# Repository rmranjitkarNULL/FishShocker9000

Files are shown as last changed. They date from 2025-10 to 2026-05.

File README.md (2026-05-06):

# FishShocker9000
A hardware/software system for high-voltage pulse generation and control, integrating custom PCB design, embedded firmware, and testing tools.

---

## Overview
FishShocker9000 was developed as a project to explore **embedded systems design, PCB layout, and high-voltage electronics**.  
The system combines custom hardware with **C/C++ firmware** to generate controlled electrical pulses, managed through a modular and extensible software stack.

---

## Hardware
- **Custom PCB Design** (schematics + board layouts)  
- Power delivery circuits for safe and reliable pulse generation  
- Signal conditioning and protection hardware  
- Mixed-signal layout considerations for high-voltage operation  

---

## Features
- Precise pulse generation and control  
- Configurable timing and waveform parameters  
- Modular design for hardware/firmware scalability  
- PCB + firmware tightly integrated for performance and safety  

---

## Repository Structure
FishShocker9000/
├── include/ # Header files
├── lib/ # Custom libraries
├── src/ # Firmware source code
├── test/ # Testing and validation scripts
├── pcb/ # PCB design files (schematics, layouts)
└── README.md # Project documentation

---

## Future Improvements
- Improve PCB design for efficiency and miniaturization  
- Expand safety features and protection circuitry  

---

TODO
-[ ] Redo Readme
-[ ] Make assembly guide
-[ ] [add](https://www.pjrc.com/teensy/loader.html)

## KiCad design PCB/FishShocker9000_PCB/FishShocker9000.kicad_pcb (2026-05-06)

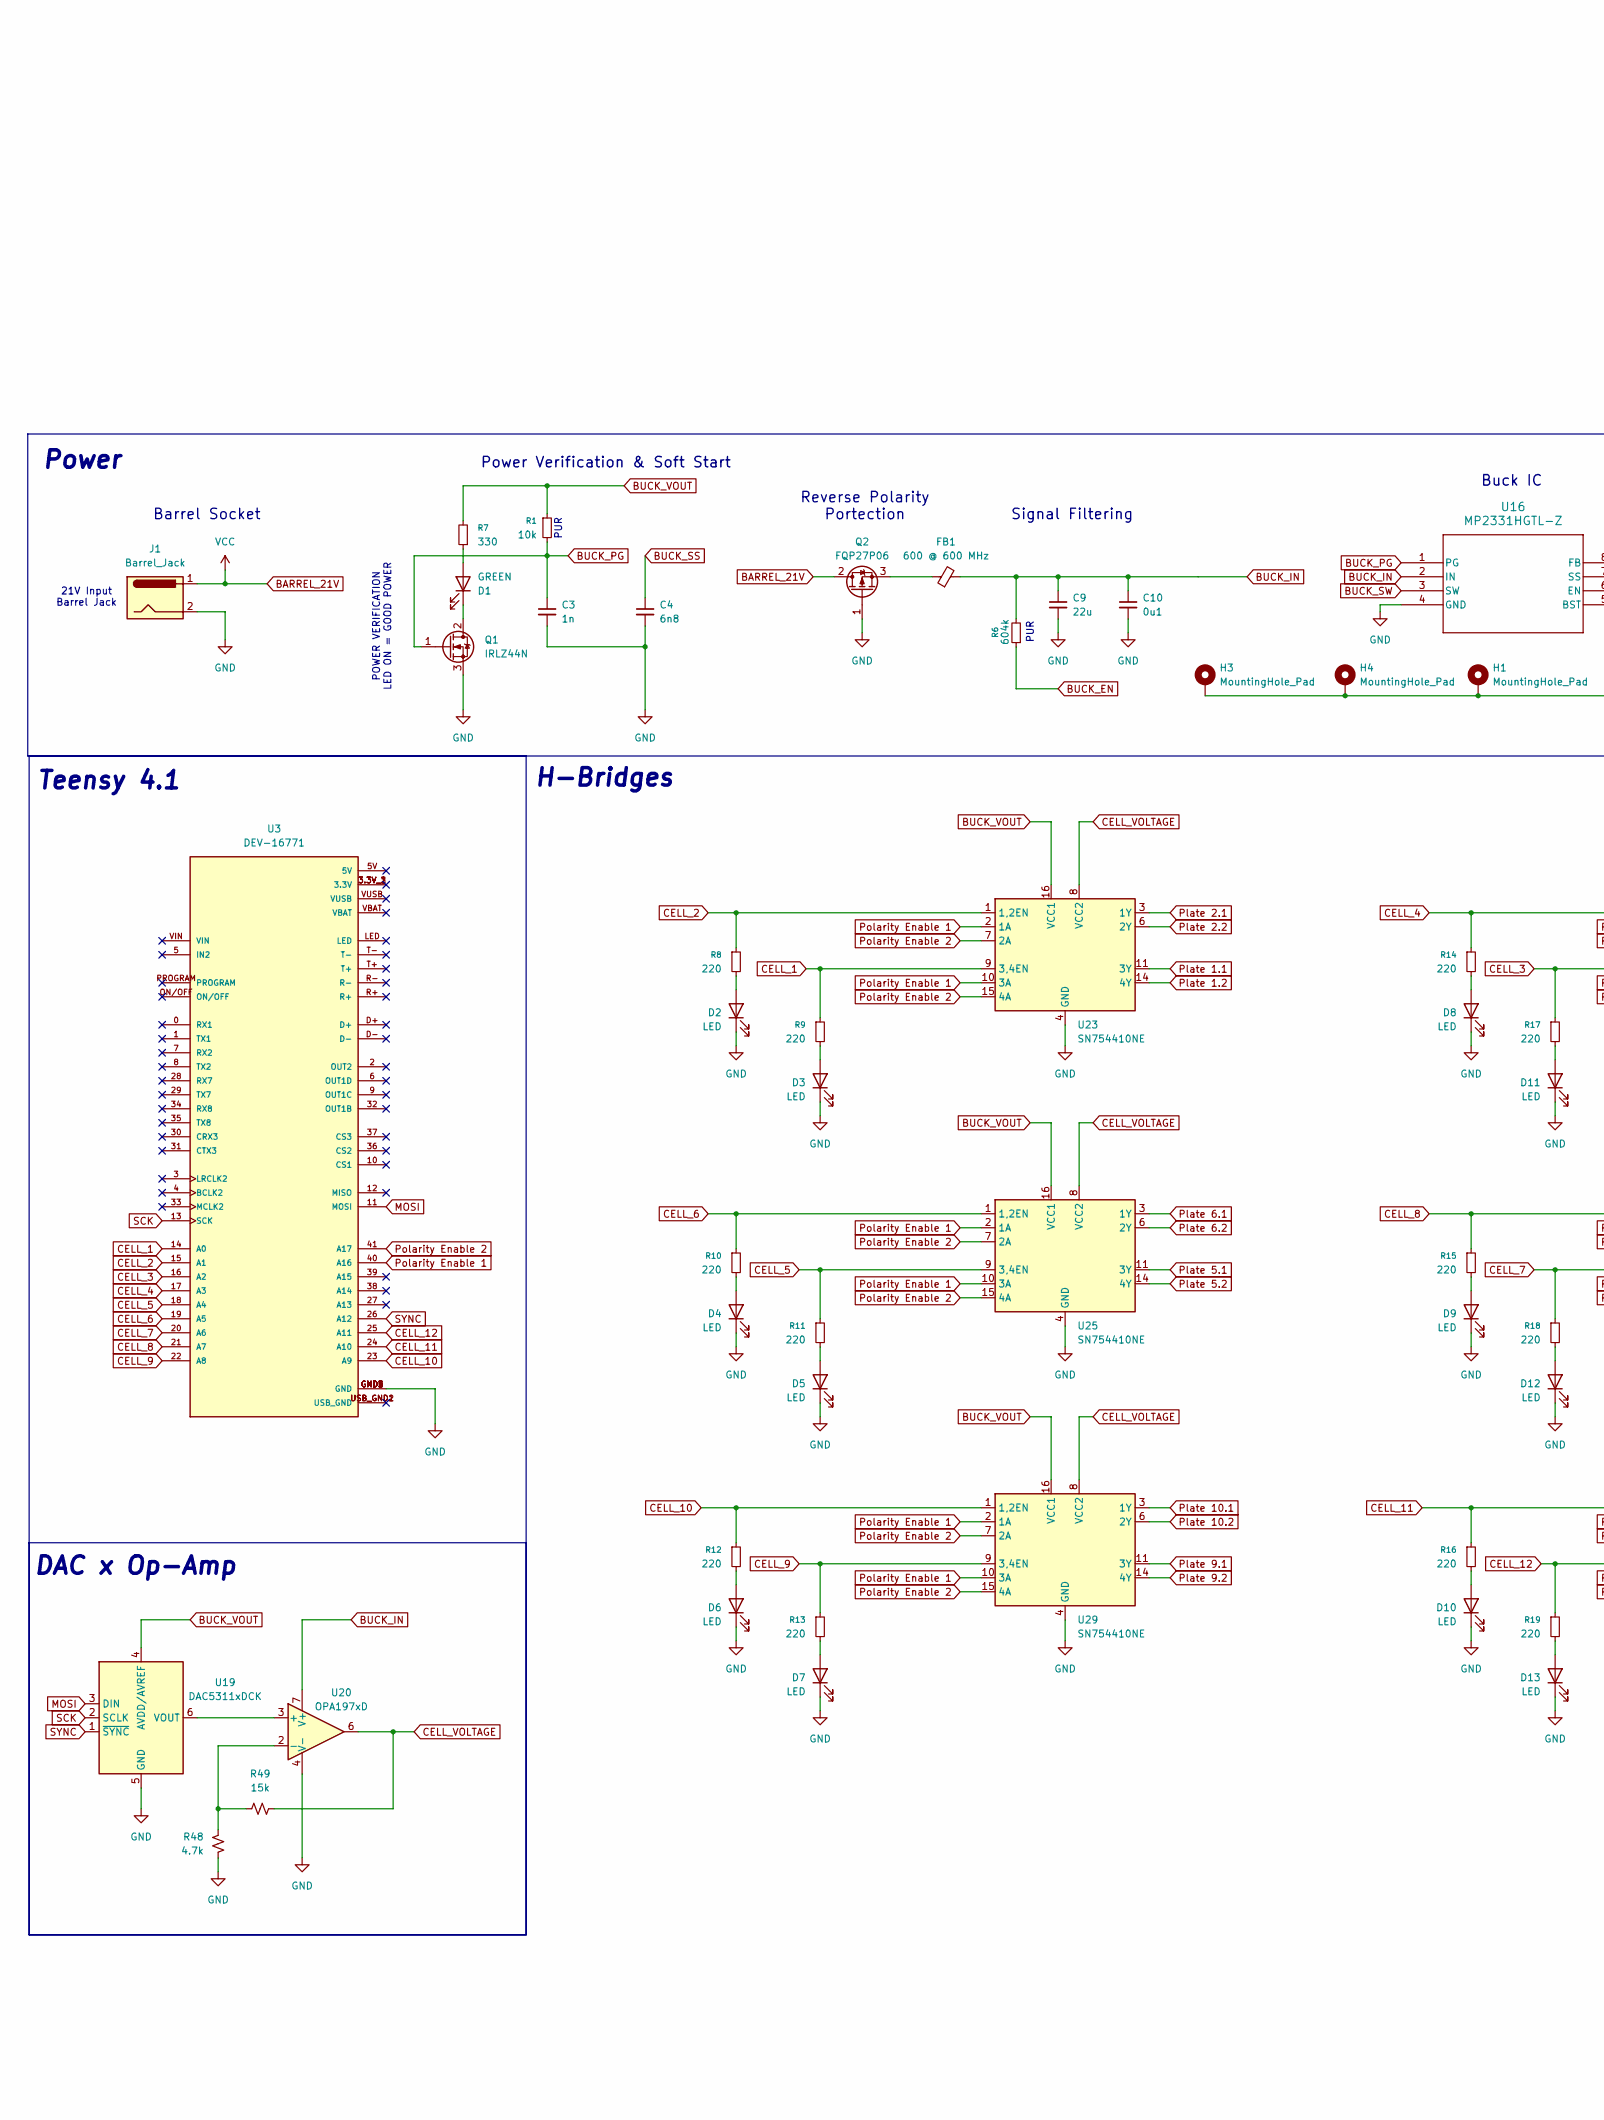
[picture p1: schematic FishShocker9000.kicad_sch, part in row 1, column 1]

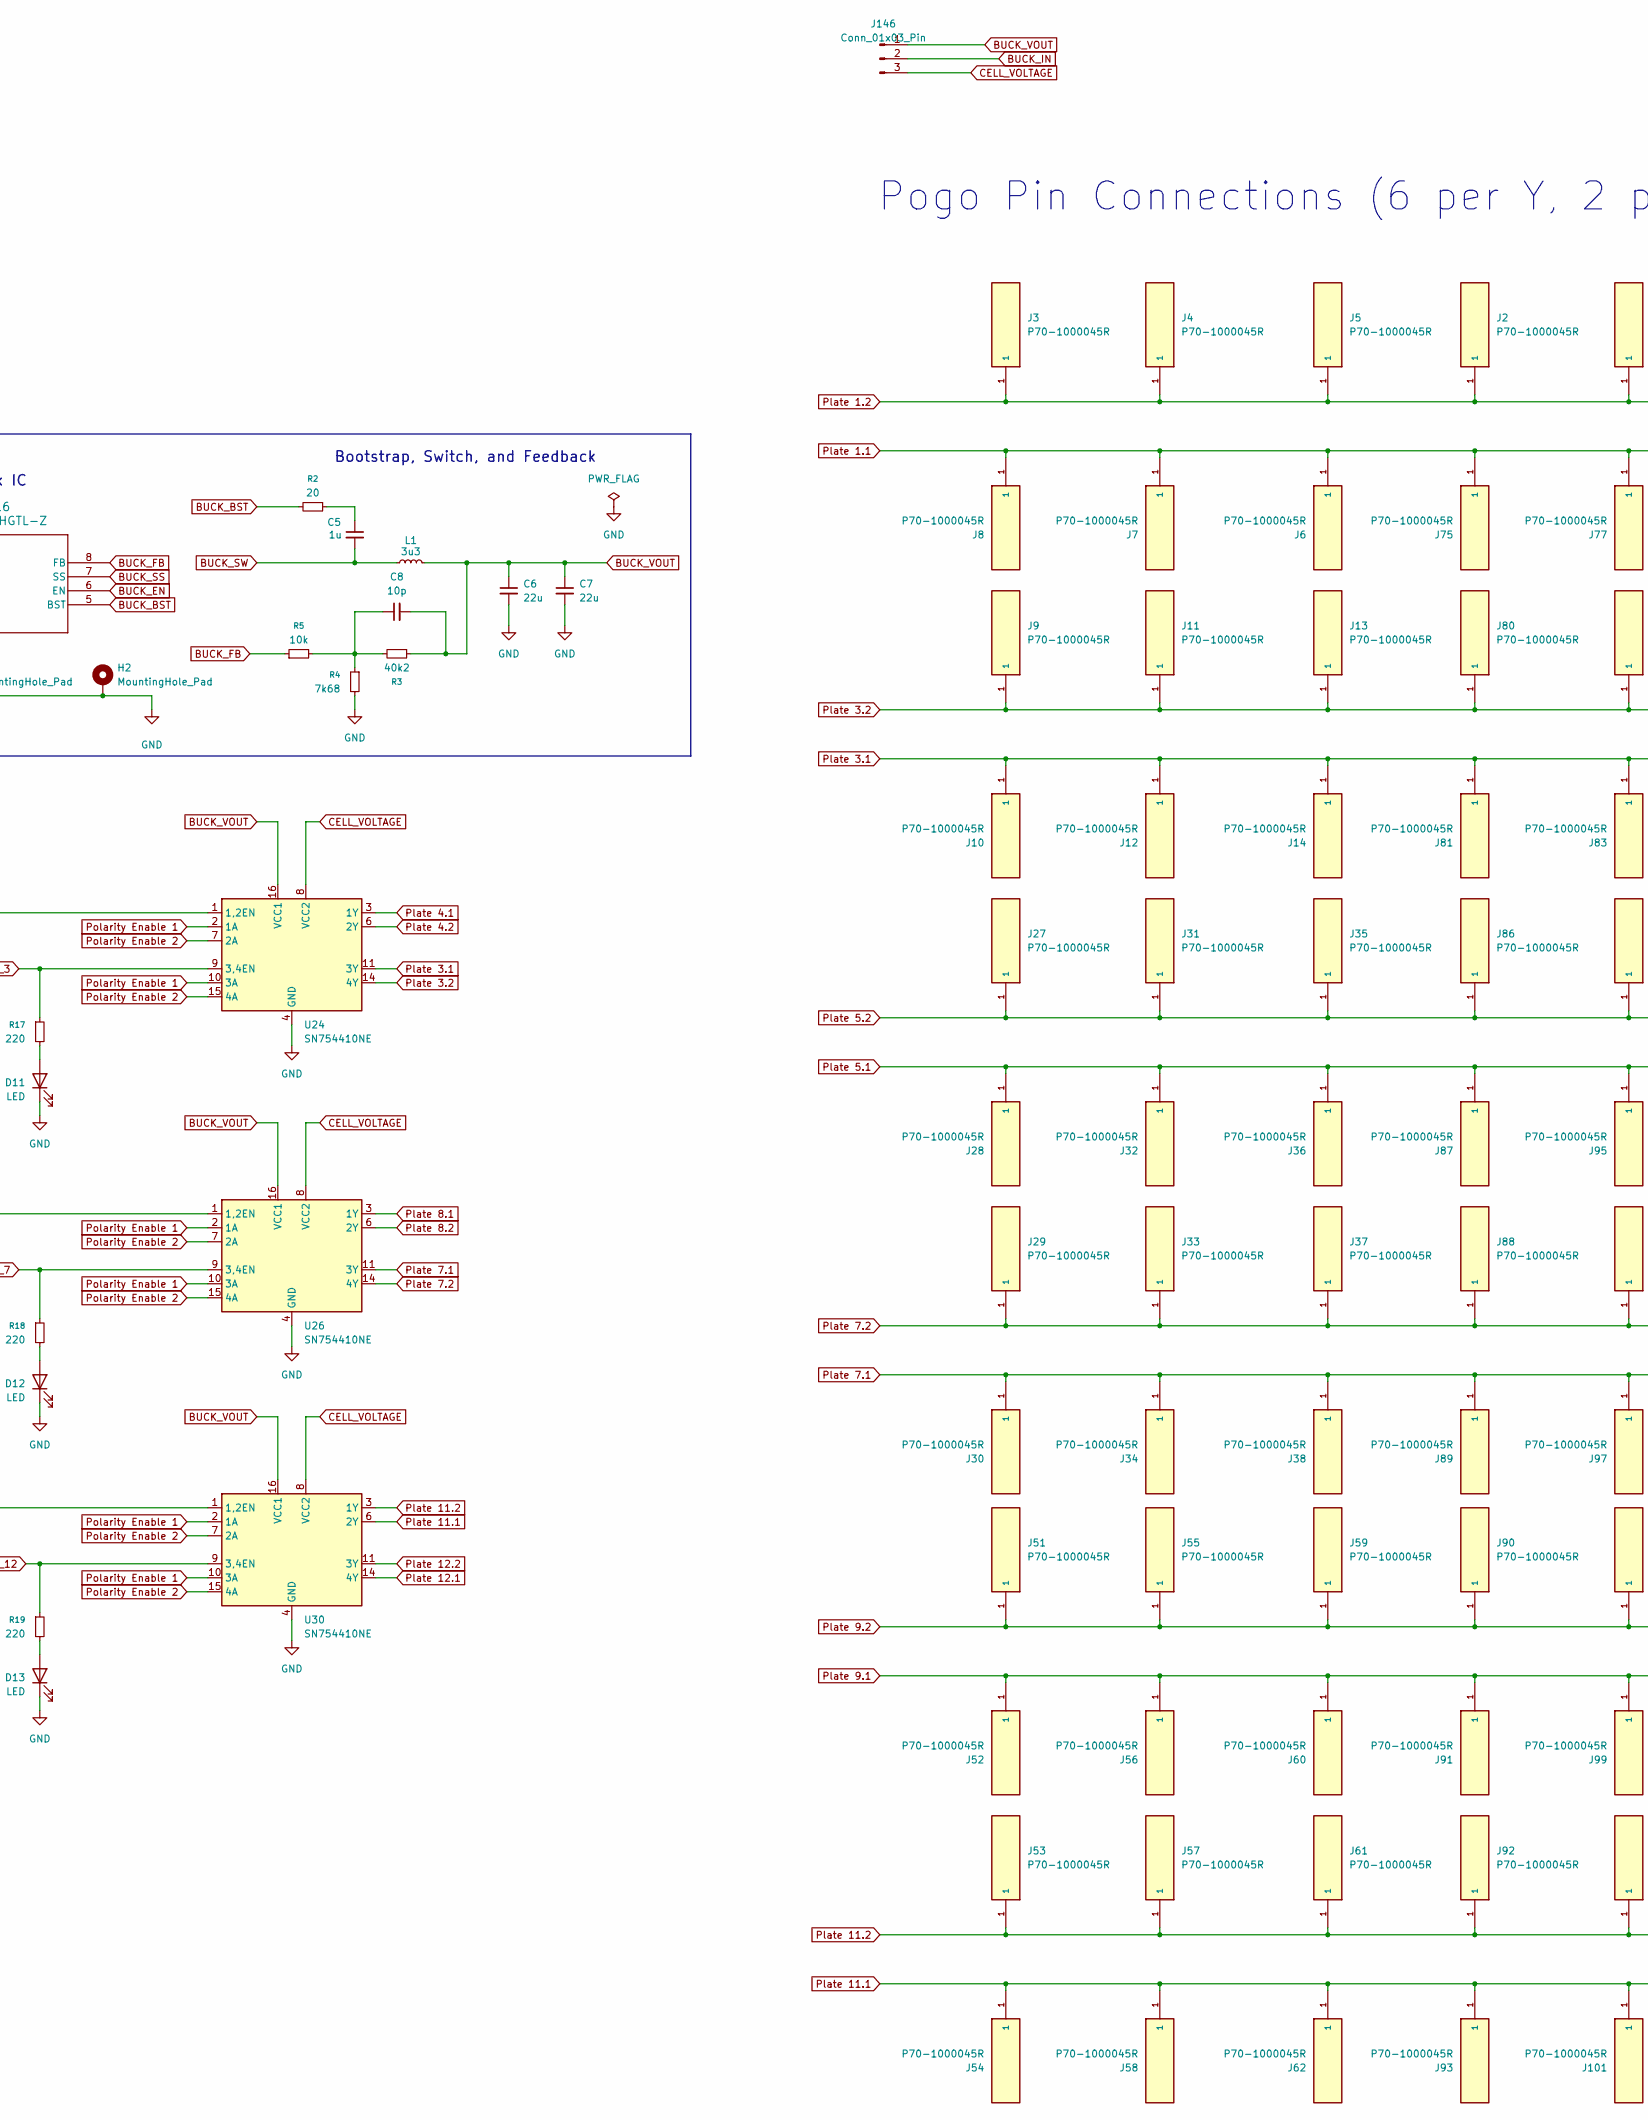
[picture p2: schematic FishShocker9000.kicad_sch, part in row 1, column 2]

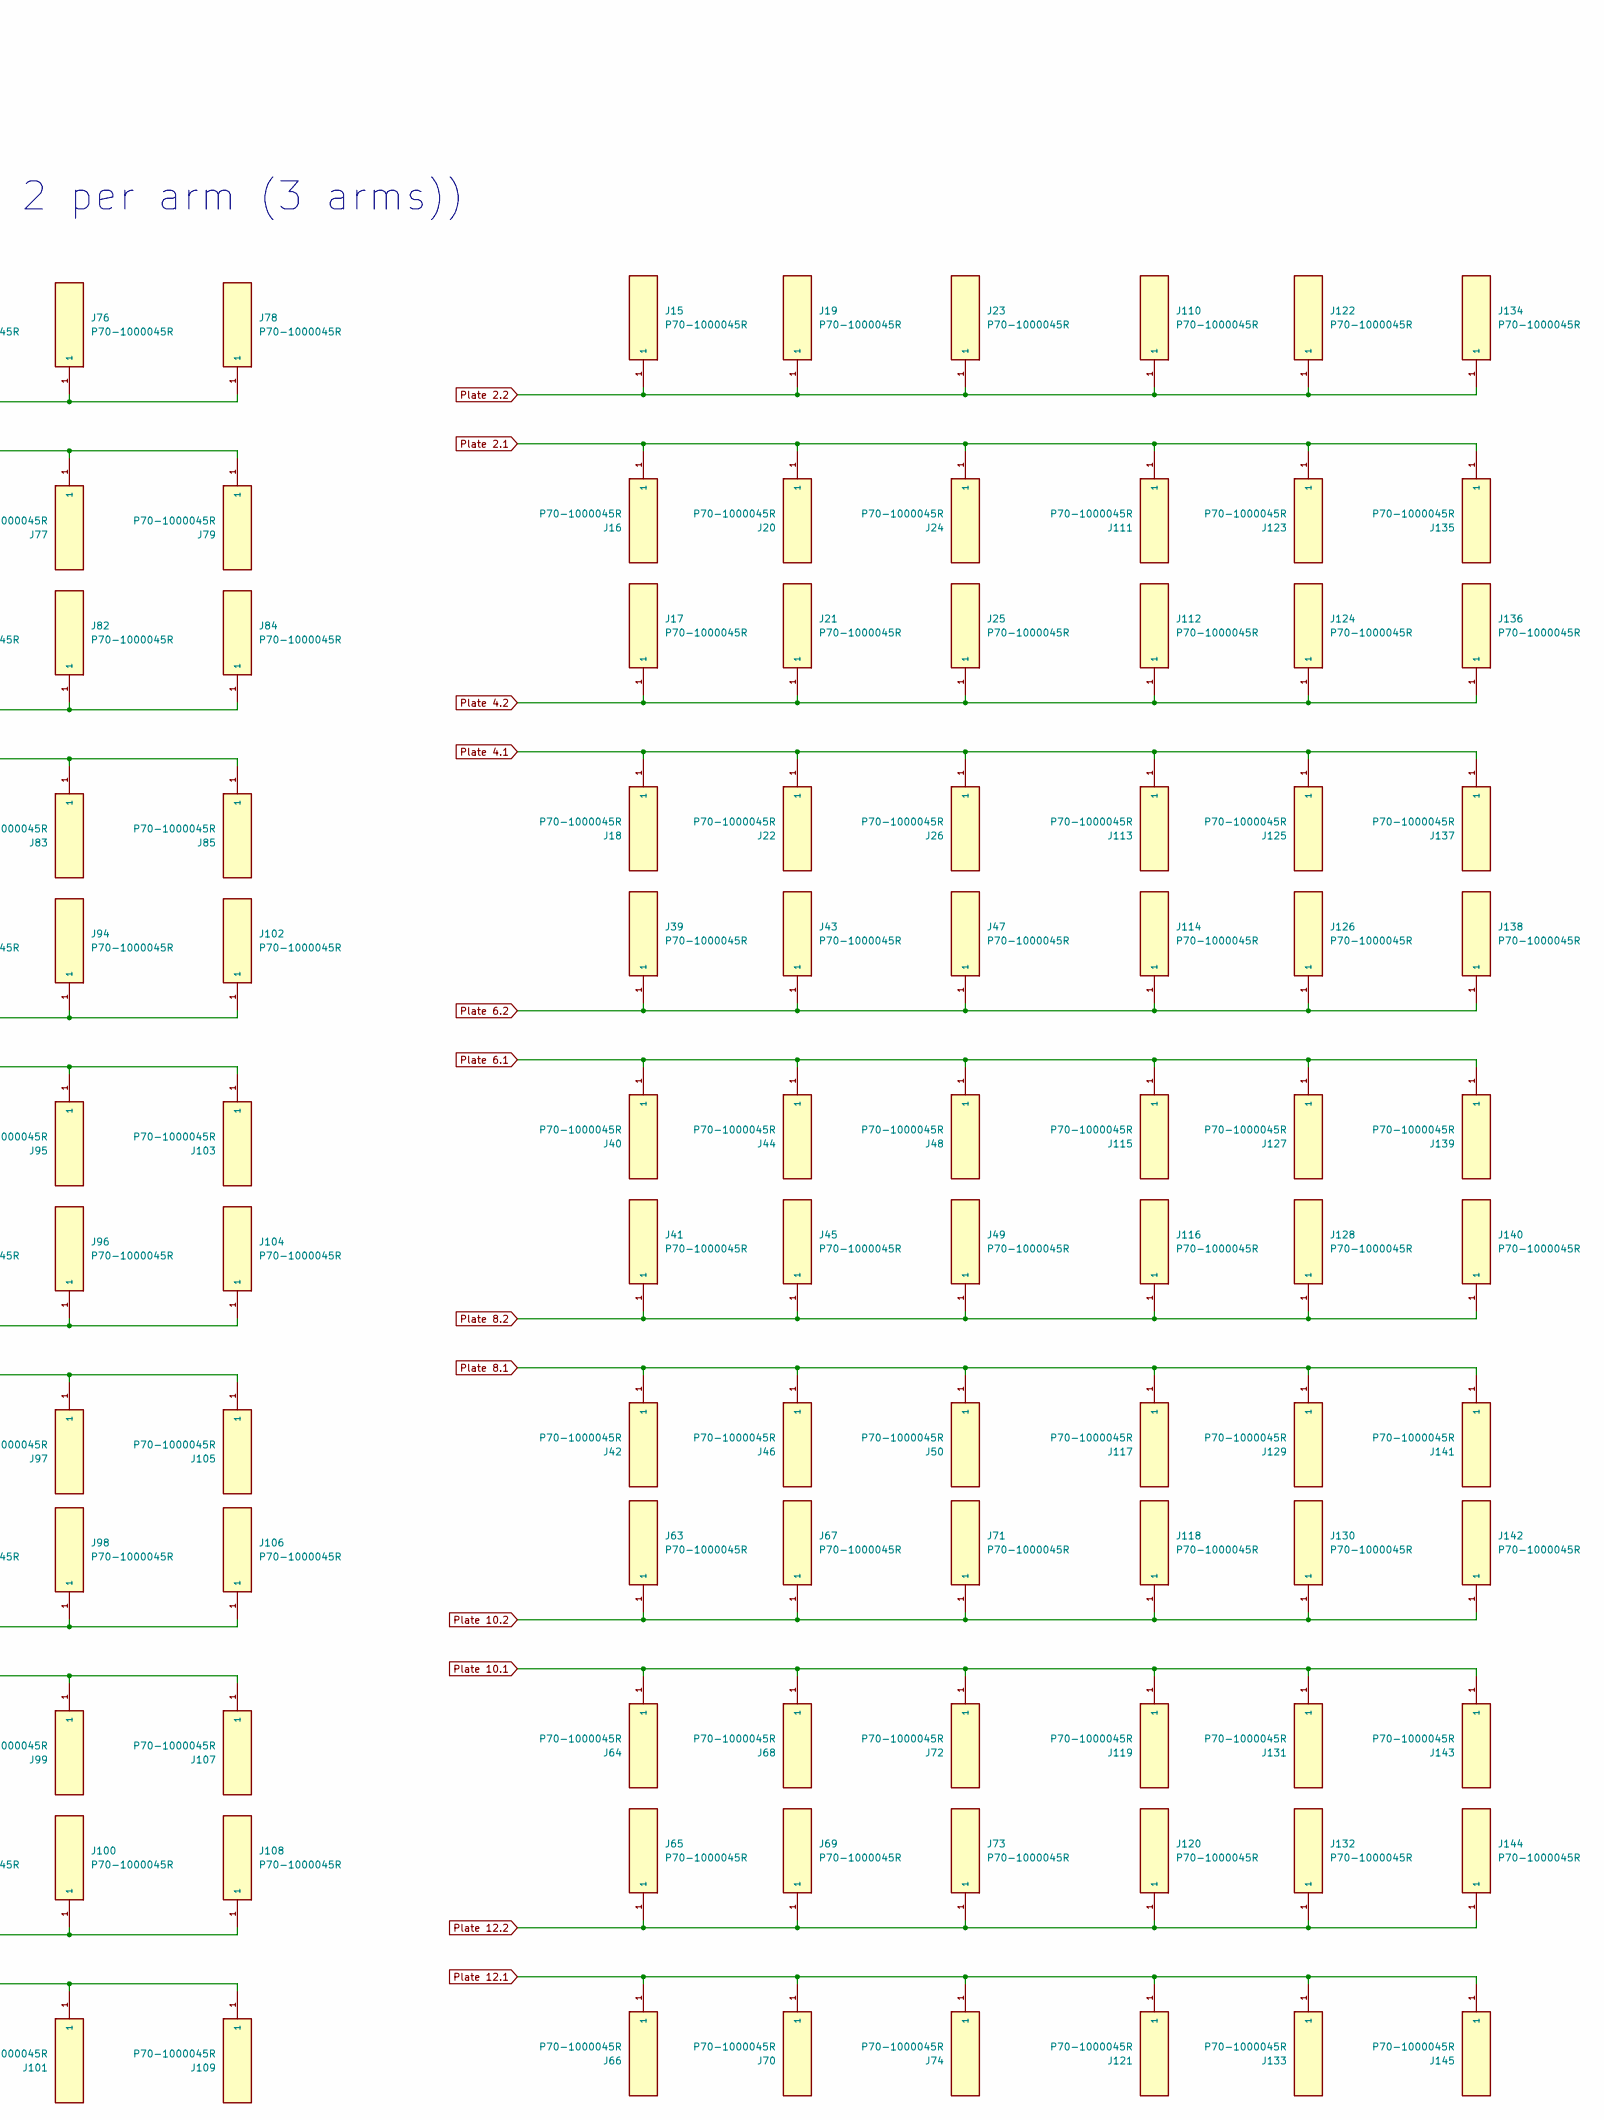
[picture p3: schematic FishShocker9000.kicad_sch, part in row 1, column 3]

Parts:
C3: 1n; C_0402_1005Metric
C4: 6n8; C_0603_1608Metric
C5: 1u; C_1206_3216Metric
C6, C7, C9: 22u; C_1206_3216Metric
C8: 10p; C_0603_1608Metric
C10: 0u1; C_0603_1608Metric
D1: GREEN; LED_0805_2012Metric
D2, D3, D4, D5, D6, D7, D8, D9, D10, D11, D12, D13: LED; LED_0805_2012Metric
FB1: 600 @ 600 MHz; L_0805_2012Metric
H1, H2, H3, H4: MountingHole_Pad; MountingHole_2.2mm_M2_DIN965_Pad
J1: Barrel_Jack; BarrelJack_CLIFF_FC681465S_SMT_Horizontal
J2, J3, J4, J5, J6, J7, J8, J9, J10, J11, J12, J13, J14, J15, J16, J17, J18, J19, J20, J21, J22, J23, J24, J25, J26, J27, J28, J29, J30, J31, J32, J33, J34, J35, J36, J37, J38, J39, J40, J41, J42, J43, J44, J45, J46, J47, J48, J49, J50, J51, J52, J53, J54, J55, J56, J57, J58, J59, J60, J61, J62, J63, J64, J65, J66, J67, J68, J69, J70, J71, J72, J73, J74, J75, J76, J77, J78, J79, J80, J81, J82, J83, J84, J85, J86, J87, J88, J89, J90, J91, J92, J93, J94, J95, J96, J97, J98, J99, J100, J101, J102, J103, J104, J105, J106, J107, J108, J109, J110, J111, J112, J113, J114, J115, J116, J117, J118, J119, J120, J121, J122, J123, J124, J125, J126, J127, J128, J129, J130, J131, J132, J133, J134, J135, J136, J137, J138, J139, J140, J141, J142, J143, J144, J145: P70-1000045R; PinHeader_1x01_P2.54mm_Vertical; PARTREV 4
J146: Conn_01x03_Pin; PinHeader_1x03_P2.54mm_Vertical
L1: 3u3; L_0805_2012Metric
Q1: IRLZ44N; TO-220-3_Vertical
Q2: FQP27P06; TO-220-3_Vertical
R1, R5: 10k; R_0805_2012Metric
R2: 20; R_0805_2012Metric
R3: 40k2; R_0805_2012Metric
R4: 7k68; R_0805_2012Metric
R6: 604k; R_0805_2012Metric
R7: 330; R_0805_2012Metric
R8, R9, R10, R11, R12, R13, R14, R15, R16, R17, R18, R19: 220; R_0805_2012Metric
R48: 4.7k; R_Axial_DIN0207_L6.3mm_D2.5mm_P10.16mm_Horizontal
R49: 15k; R_Axial_DIN0207_L6.3mm_D2.5mm_P10.16mm_Horizontal
U3: DEV-16771; Teensy 4.1; PARTREV 4.1
U16: MP2331HGTL-Z; SOT583_MP2331H
U19: DAC5311xDCK; SOT-363_SC-70-6
U20: OPA197xD; SOIC-8_3.9x4.9mm_P1.27mm
U23, U24, U25, U26, U29, U30: SN754410NE; DIP-16_W7.62mm

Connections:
BARREL_21V: J1.1, Q2.2 (D)
BUCK_BST: R2.2, U16.5 (BST)
BUCK_EN: R6.1, U16.6 (EN)
BUCK_FB: R5.1, U16.8 (FB)
BUCK_IN: C9.1, C10.1, FB1.2, J146.2, R6.2, U16.2 (IN), U20.7 (V+)
BUCK_PG: C3.1, Q1.1 (G), R1.2, U16.1 (PG)
BUCK_SS: C4.1, U16.7 (SS)
BUCK_SW: C5.2, L1.1, U16.3 (SW)
BUCK_VOUT: C6.1, C7.1, C8.2, J146.1, L1.2, R1.1, R3.1, R7.2, U19.4 (AVDD/AVREF), U23.16 (VCC1), U24.16 (VCC1), U25.16 (VCC1), U26.16 (VCC1), U29.16 (VCC1), U30.16 (VCC1)
CELL_1: R9.1, U3.14 (A0), U23.9 (3,4EN)
CELL_2: R8.1, U3.15 (A1), U23.1 (1,2EN)
CELL_3: R17.1, U3.16 (A2), U24.9 (3,4EN)
CELL_4: R14.1, U3.17 (A3), U24.1 (1,2EN)
CELL_5: R11.1, U3.18 (A4), U25.9 (3,4EN)
CELL_6: R10.1, U3.19 (A5), U25.1 (1,2EN)
CELL_7: R18.1, U3.20 (A6), U26.9 (3,4EN)
CELL_8: R15.1, U3.21 (A7), U26.1 (1,2EN)
CELL_9: R13.1, U3.22 (A8), U29.9 (3,4EN)
CELL_10: R12.1, U3.23 (A9), U29.1 (1,2EN)
CELL_11: R16.1, U3.24 (A10), U30.1 (1,2EN)
CELL_12: R19.1, U3.25 (A11), U30.9 (3,4EN)
CELL_VOLTAGE: J146.3, R49.2, U20.6, U23.8 (VCC2), U24.8 (VCC2), U25.8 (VCC2), U26.8 (VCC2), U29.8 (VCC2), U30.8 (VCC2)
GND: C3.2, C4.2, C6.2, C7.2, C9.2, C10.2, D2.1 (K), D3.1 (K), D4.1 (K), D5.1 (K), D6.1 (K), D7.1 (K), D8.1 (K), D9.1 (K), D10.1 (K), D11.1 (K), D12.1 (K), D13.1 (K), H1.1, H2.1, H3.1, H4.1, J1.2, Q1.3 (S), Q2.1 (G), R4.2, R48.2, U3.GND1 (GND), U3.GND2 (GND), U3.GND3 (GND), U3.GND4 (GND), U3.GND5 (GND), U16.4 (GND), U19.5 (GND), U20.4 (V-), U23.4 (GND), U23.5 (GND), U23.12 (GND), U23.13 (GND), U24.4 (GND), U24.5 (GND), U24.12 (GND), U24.13 (GND), U25.4 (GND), U25.5 (GND), U25.12 (GND), U25.13 (GND), U26.4 (GND), U26.5 (GND), U26.12 (GND), U26.13 (GND), U29.4 (GND), U29.5 (GND), U29.12 (GND), U29.13 (GND), U30.4 (GND), U30.5 (GND), U30.12 (GND), U30.13 (GND)
MOSI: U3.11 (MOSI), U19.3 (DIN)
unnamed: C5.1, R2.1
unnamed: C8.1, R3.2, R4.1, R5.2
unnamed: D1.2 (A), R7.1
unnamed: D1.1 (K), Q1.2 (D)
unnamed: D2.2 (A), R8.2
unnamed: D3.2 (A), R9.2
unnamed: D4.2 (A), R10.2
unnamed: D5.2 (A), R11.2
unnamed: D6.2 (A), R12.2
unnamed: D7.2 (A), R13.2
unnamed: D8.2 (A), R14.2
unnamed: D9.2 (A), R15.2
unnamed: D10.2 (A), R16.2
unnamed: D11.2 (A), R17.2
unnamed: D12.2 (A), R18.2
unnamed: D13.2 (A), R19.2
unnamed: FB1.1, Q2.3 (S)
unnamed: U19.6 (VOUT), U20.3 (+)
unnamed: R48.1, R49.1, U20.2 (-)
Plate 1.1: J6.1, J7.1, J8.1, J75.1, J77.1, J79.1, U23.11 (3Y)
Plate 1.2: J2.1, J3.1, J4.1, J5.1, J76.1, J78.1, U23.14 (4Y)
Plate 2.1: J16.1, J20.1, J24.1, J111.1, J123.1, J135.1, U23.3 (1Y)
Plate 2.2: J15.1, J19.1, J23.1, J110.1, J122.1, J134.1, U23.6 (2Y)
Plate 3.1: J10.1, J12.1, J14.1, J81.1, J83.1, J85.1, U24.11 (3Y)
Plate 3.2: J9.1, J11.1, J13.1, J80.1, J82.1, J84.1, U24.14 (4Y)
Plate 4.1: J18.1, J22.1, J26.1, J113.1, J125.1, J137.1, U24.3 (1Y)
Plate 4.2: J17.1, J21.1, J25.1, J112.1, J124.1, J136.1, U24.6 (2Y)
Plate 5.1: J28.1, J32.1, J36.1, J87.1, J95.1, J103.1, U25.11 (3Y)
Plate 5.2: J27.1, J31.1, J35.1, J86.1, J94.1, J102.1, U25.14 (4Y)
Plate 6.1: J40.1, J44.1, J48.1, J115.1, J127.1, J139.1, U25.3 (1Y)
Plate 6.2: J39.1, J43.1, J47.1, J114.1, J126.1, J138.1, U25.6 (2Y)
Plate 7.1: J30.1, J34.1, J38.1, J89.1, J97.1, J105.1, U26.11 (3Y)
Plate 7.2: J29.1, J33.1, J37.1, J88.1, J96.1, J104.1, U26.14 (4Y)
Plate 8.1: J42.1, J46.1, J50.1, J117.1, J129.1, J141.1, U26.3 (1Y)
Plate 8.2: J41.1, J45.1, J49.1, J116.1, J128.1, J140.1, U26.6 (2Y)
Plate 9.1: J52.1, J56.1, J60.1, J91.1, J99.1, J107.1, U29.11 (3Y)
Plate 9.2: J51.1, J55.1, J59.1, J90.1, J98.1, J106.1, U29.14 (4Y)
Plate 10.1: J64.1, J68.1, J72.1, J119.1, J131.1, J143.1, U29.3 (1Y)
Plate 10.2: J63.1, J67.1, J71.1, J118.1, J130.1, J142.1, U29.6 (2Y)
Plate 11.1: J54.1, J58.1, J62.1, J93.1, J101.1, J109.1, U30.6 (2Y)
Plate 11.2: J53.1, J57.1, J61.1, J92.1, J100.1, J108.1, U30.3 (1Y)
Plate 12.1: J66.1, J70.1, J74.1, J121.1, J133.1, J145.1, U30.14 (4Y)
Plate 12.2: J65.1, J69.1, J73.1, J120.1, J132.1, J144.1, U30.11 (3Y)
Polarity Enable 1: U3.40 (A16), U23.2 (1A), U23.10 (3A), U24.2 (1A), U24.10 (3A), U25.2 (1A), U25.10 (3A), U26.2 (1A), U26.10 (3A), U29.2 (1A), U29.10 (3A), U30.2 (1A), U30.10 (3A)
Polarity Enable 2: U3.41 (A17), U23.7 (2A), U23.15 (4A), U24.7 (2A), U24.15 (4A), U25.7 (2A), U25.15 (4A), U26.7 (2A), U26.15 (4A), U29.7 (2A), U29.15 (4A), U30.7 (2A), U30.15 (4A)
SCK: U3.13 (SCK), U19.2 (SCLK)
SYNC: U3.26 (A12), U19.1 (~SYNC)

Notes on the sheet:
POWER VERIFICATION LED ON = GOOD POWER
Pogo Pin Connections (6 per Y, 2 per arm (3 arms))
PUR
Barrel Socket
DAC x Op-Amp
Signal Filtering
Power Verification & Soft Start
Reverse Polarity Portection
H-Bridges
Teensy 4.1
Bootstrap, Switch, and Feedback
Buck IC
21V Input Barrel Jack
Power

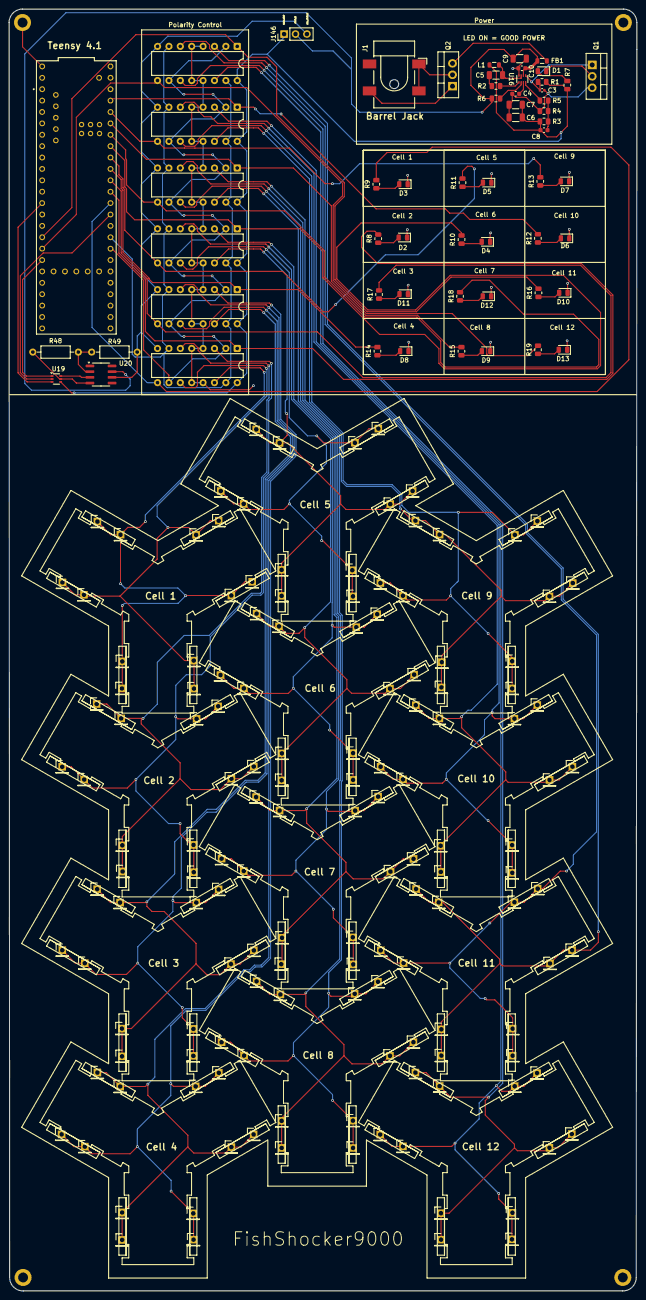
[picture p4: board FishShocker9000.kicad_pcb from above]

Board: 2 copper layers, 140.0 x 285.9 mm, 206 parts (0 on the bottom side), 71 nets.

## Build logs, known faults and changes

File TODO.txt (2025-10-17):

Future PCB Improvements:
  - Add more current limiting resistors
  - double check BUCK IC setup, put current resistor from valid output to softstart
  - FIx barrel jack footprint
  - Add power switch tot he barrel jack itself
  - Buck convert from 12-5.3v for headroom
  - Add voltage buffers to isolate the current when going into the H bridge IC
  - Add more debugging holes and ground terminals for easier debugging

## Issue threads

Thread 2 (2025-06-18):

Implement CAN

rmranjitkarNULL, 2025-06-18:
Implement CAN for recieving signals form the camera and sending out to the correct gpio pin

Closed 2025-07-30.

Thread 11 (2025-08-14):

PCB updates

rmranjitkarNULL, 2025-08-14:
Update the PCB to take in IC Sockets, bigger and more test points, smaller mosfets, and better routing.

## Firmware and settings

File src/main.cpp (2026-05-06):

#include <Arduino.h>
#include "shock.h"
#include "polarity.h"
#include "sample.h"
#include "SerialTransfer.h"
#include "spi_dac.h"

// Serial Transfer from python script
SerialTransfer myTransfer;

// Cells
Cell cell_1 = {CELL1};
Cell cell_2 = {CELL2};
Cell cell_3 = {CELL3};
Cell cell_4 = {CELL4};
Cell cell_5 = {CELL5};
Cell cell_6 = {CELL6};
Cell cell_7 = {CELL7};
Cell cell_8 = {CELL8};
Cell cell_9 = {CELL9};
Cell cell_10 = {CELL10};
Cell cell_11 = {CELL11};
Cell cell_12 = {CELL12};

Cell* cells[] = {&cell_1, &cell_2, &cell_3, &cell_4, &cell_5, &cell_6,
                       &cell_7, &cell_8, &cell_9, &cell_10, &cell_11, &cell_12};
                       
const uint8_t NUM_CELLS = sizeof(cells) / sizeof(cells[0]);

// Declare Variable to store for pyserial
char ch;

// key Mapping to cells
const char keyMap[NUM_CELLS] = {
    '1','2','3','4','5','6','7','8','9','0','-','='
};

uint32_t keyLastSeen[12] = {0};
const uint32_t KEY_TIMEOUT = 50;  // ms or ticks


void setup() {

  // Initialize Serial
  Serial.begin(115200);
  while (!Serial);
  Serial.println("Initializing Setup\n");

  // Initialize shock setup (Pins, Timers, etc.)
  shockSetup();

  // Initialize polarity setup (Pins, Timers, etc.)
  polarity_setup();

  // Initialize SPI and DAC
  setupDAC();

  // Initialize Serial for python script
  myTransfer.begin(Serial);

  Serial.println("\nFishShocker9000: Setup Complete\n");

  // * Testing: Set all cells to have the fish "in_zone" so the shocks can turn on
  for(int i = 0; i < NUM_CELLS; i++){
      cells[i]->in_zone = true;
  }

  writeDAC(0.75);

} 

void loop() {

  // if (myTransfer.available()) {

  //   // Receive a single character
  //   myTransfer.rxObj(ch);

  //   // Echo back to Python (optional, but matches your Python code)
  //   uint16_t sendSize = 0;
  //   sendSize += myTransfer.txObj(ch);
  //   myTransfer.sendData(sendSize);

  //   // Update matching cell
  //   for (int i = 0; i < NUM_CELLS; i++) {
  //     if (ch == keyMap[i]) {
  //       cells[i]->in_zone = true;
  //       keyLastSeen[i] = shockCounter;
  //     }
  //   }

  //   ch = '\0';
  // }

  // // Handle Key Timeouts
  // for (int i = 0; i < NUM_CELLS; i++) {
  //   if (cells[i]->in_zone &&
  //       (shockCounter - keyLastSeen[i] > KEY_TIMEOUT)) {
  //     cells[i]->in_zone = false;
  //   }
  // } 



  // Run the shock controller
  for (int i = 0; i < NUM_CELLS; i++) {
    controlShock(cells[i]);
  }


}

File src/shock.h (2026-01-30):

#pragma once

// Libraries
#include <Arduino.h>

// Definition
#define DELTA_SHOCK 250                                   // Time of shock in ms
#define DELTA_REST 500                                   // Time of rest in ms
#define SHOCK_CYCLE (DELTA_SHOCK + DELTA_REST)           // Shock cycle period
#define SHOCK_TIMER_INTERVAL 1000                        // Timer configuration for shock timer
#define CELL1 A0                                         // Pinout for sending signal
#define CELL2 A1                                         // Pinout for sending signal
#define CELL3 A2                                         // Pinout for sending signal
#define CELL4 A3                                         // Pinout for sending signal
#define CELL5 A4                                         // Pinout for sending signal
#define CELL6 A5                                         // Pinout for sending signal
#define CELL7 A6                                         // Pinout for sending signal
#define CELL8 A7                                         // Pinout for sending signal
#define CELL9 A8                                         // Pinout for sending signal
#define CELL10 A9                                        // Pinout for sending signal
#define CELL11 A10                                       // Pinout for sending signal
#define CELL12 A11                                       // Pinout for sending signal

// Cell Struct
struct Cell{
    int cell_id;                                         //
    volatile bool in_zone = false;
    bool shock_on = false;
    uint32_t last_toggle_time = 0;
};

// Timer Object
extern IntervalTimer shock_timer;

// Global Variables
extern volatile uint32_t shockCounter;

extern Cell* cells[];
extern const uint8_t NUM_CELLS;


/* void count_shock()
 * @brief Timer callback function that increments the shock counter
 * 
 * This function is triggered every millisecond. It increments the `shock_counter` until it reaches
 * the defined SHOCK_CYCLE period (shock duration + rest duration), then resets it back to zero.
 * Used to schedule shock output within a cycle.
 * 
 * @param: NA
 * @return: NA
 */
void countShock();

/* void shock_setup()
 * @brief Initializes GPIO pins and timer for the shock mechanism
 * 
 * Sets the shock output pin to OUTPUT mode and initializes the timer that controls
 * the shock pulse cycle.
 * 
 * @param: NA
 * @return: NA
 */
void shockSetup();

/* void send_signal(Cell *cell, int level)
 * @brief Sends a HIGH or LOW to the corresponding pin
 * 
 * Sends the corresponding level to the corresponding GPIO pin, either HIGH (3.3v)
 * or LOW (0v). Utilizes the cell structure to find the corresponding GPIO pin to
 * send out the signal
 * 
 * @param: Cell *cell - Cell to send the signal to
 * @param: int level - HIGH or LOW (3.3v or 0v)
 * @return: NA
 */
void sendSignal(Cell *cell, int level);

/* void control_shock(Cell *cell)
 * @brief Controls the shock being sent out
 * 
 * Sends a signal (shock) to the corresponding cell at the rate desired in
 * the delta parameters. Turns off the shock if the fish is no longer in the area
 * 
 * @param: Cell *cell - Cell to send the signal to
 * @return: NA
 */
void controlShock(Cell *cell);

/* void check_start(Cell *cell)
 * @brief Checks if the cell is just starting a shock
 * 
 * If the fish enters the area, this will start the shock on the correspondign cell
 * without waiting the rest period.
 * 
 * @param: Cell *cell - Cell to send the signal to
 * @return: Bool
 */
bool checkStart(Cell *cell);

/* void check_shock(Cell *cell, uint32_t curr_time)
 * @brief Checks if the fish has been shocked for the delta shock time
 * 
 * Checks if the fish has been shocked for the delta shock time.
 * 
 * @param: Cell *cell -> Cell to send the signal to
 * @param: uint32_t time -> The "Current" time at this function call
 * @return: Bool
 */
bool checkShock(Cell *cell, uint32_t curr_time);

/* void check_rest(Cell *cell, uint32_t curr_time)
 * @brief Checks if the fish has not been shocked for the delta rest time
 * 
 * Checks if the fish has not been shocked for the delta rest time
 * 
 * @param: Cell *cell -> Cell to send the signal to
 * @param: uint32_t time -> The "Current" time at this function call
 * @return: NA
 */
bool checkRest(Cell *cell, uint32_t curr_time);

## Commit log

2025-06-13 Added planned PCB
    [FishShocker9000.kicad_pcb, FishShocker9000.kicad_sch]
2025-06-13 changed the supply rail to 15v, changed op amp model to LM358
    [FishShocker9000.kicad_sch]
2025-06-18 fixed pcb with correct IC and finalized it for one cell
    [FishShocker9000.kicad_sch]
2025-06-26 added fifo (untested) source code to code base
    [FishShocker9000.kicad_sch]
2025-06-26 Converted format to snake case for readability
2025-07-01 Added barebones component to the mechanics (No Values)
    [FishShocker9000.kicad_sch]
2025-07-01 Finalized Power Schematic and Op amp connections
    [FishShocker9000.kicad_sch]
2025-07-10 Fixed serial data issue
    [main.cpp, shock.cpp]
2025-07-15 Added values to passive components. Need to add various footprints and change pmos transistor to FQP47P06.
    [FishShocker9000.kicad_sch]
2025-07-16 changed some values for the PCB
2025-07-16 Added CAN Bus Tranciever and Pogo Pins
    [FishShocker9000.kicad_sch]
2025-07-16 Made general layout for PCB
    [FishShocker9000.csv, FishShocker9000.kicad_pcb, FishShocker9000.kicad_sch]
2025-07-17 routed PCB except for GND and Pogo Pins
    [FishShocker9000.kicad_pcb, FishShocker9000.kicad_sch]
2025-07-18 New draft of final PCB layout
    [FishShocker9000.kicad_pcb]
2025-07-18 Changed Layout to eb more clean
    [FishShocker9000.kicad_pcb, FishShocker9000.kicad_sch]
2025-07-22 Made changes to the SChematic. Now use DAC instead of sevberal op amps
2025-07-23 added various items to the schematic
    [FishShocker9000.kicad_pcb, FishShocker9000.kicad_sch]
2025-07-23 Made Changes but not complete PCB. Gonna reformat
    [FishShocker9000.kicad_pcb, FishShocker9000.kicad_sch, freerouting.dsn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]
2025-07-23 Rerouted PCB layout to actually fit and work. Need to connect Pogo Pins
    [FishShocker9000.kicad_pcb, FishShocker9000.kicad_sch]
2025-07-23 Fixed some other issues. Pogo Pins still not connected
    [FishShocker9000.kicad_pcb]
2025-07-25 Placed Pogo Pins
    [FishShocker9000.kicad_pcb]
2025-07-25 Saved Pogo Pin Changes
    [FishShocker9000.kicad_pcb]
2025-07-25 Routed all plates. Messy, gonna try and reroute to be neater
    [FishShocker9000.kicad_pcb]
2025-07-28 Fixed Teensy being double powered
    [FishShocker9000.kicad_pcb, FishShocker9000.kicad_sch]
2025-07-28 Added testing headers
    [FishShocker9000.kicad_pcb, FishShocker9000.kicad_sch]
2025-07-28 removed USB gnd
    [FishShocker9000.kicad_pcb, FishShocker9000.kicad_sch]
2025-07-28 Fixed Corruption issues
    [FishShocker9000.kicad_pcb]
2025-07-28 Fixed more corruption
    [FishShocker9000.kicad_pcb, FishShocker9000.kicad_sch]
2025-07-30 Changed pogo pin footprints to connector, fixed routing, removed ferrite bead
    [FishShocker9000.kicad_pcb, FishShocker9000.kicad_sch, freerouting.dsn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]
2025-08-14 Fixed some syntax errors. Verifying New teensy pins
    [main.cpp, shock.cpp]
2025-08-14 Fixed corrupted PCB
    [FishShocker9000.csv, FishShocker9000.kicad_sch, freerouting.dsn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]
2025-08-14 Fixed corrupted PCB again
    [FishShocker9000.kicad_pcb, FishShocker9000.kicad_sch]
2025-08-14 Verified Cell Pin connections. Need to fix sender.py to toggle Cell pins
    [main.cpp, shock.cpp, shock.h]
2025-08-15 added function prototype and definitions
2025-08-18 Fixed syntax. Testing DAC
    [main.cpp, polarity.cpp, spi_dac.cpp]
2025-08-19 DAC Testing
    [FishShocker9000.kicad_pcb]
2025-08-19 Fixed SPI line issue: DO NOT USE THE BUILT IN LED NO MATTER WHAT
    [main.cpp, shock.cpp, spi_dac.cpp]
2025-08-19 I hate LEDs
2025-08-20 Changed TODO and Gitignore
    [FishShocker9000.kicad_pcb]
2025-10-16 Added timer test
2025-10-17 DAC values are close enough. Weird offset error, but its close to the desired values.
    [main.cpp, spi_dac.cpp]
2026-05-06 remade git ignore
    [FishShocker9000.kicad_pcb, FishShocker9000.kicad_sch]
